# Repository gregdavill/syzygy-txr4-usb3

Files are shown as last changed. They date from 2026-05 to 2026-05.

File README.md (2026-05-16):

# SYZYGY-TXR4-USB3 breakout

SYZYGY is an FPGA expansion standard for medium to high speed interfaces. Learn more and check out the specifications here: [https://syzygyfpga.io/](https://syzygyfpga.io/)

---

## What is it

A breakout to connect SYZYGYs 5Gbit serdes lanes through to a USB-C connector

Running the gateware luna stack on the FPGA can enumerate as a USB3 device.

## Folder structure

```
kicad-src: KiCad v6 source files
production:
 - Gerbers:      [project]_gerbers.zip
 - Schematic:    [project].pdf
 - Board render: [project].png
```

## Photo

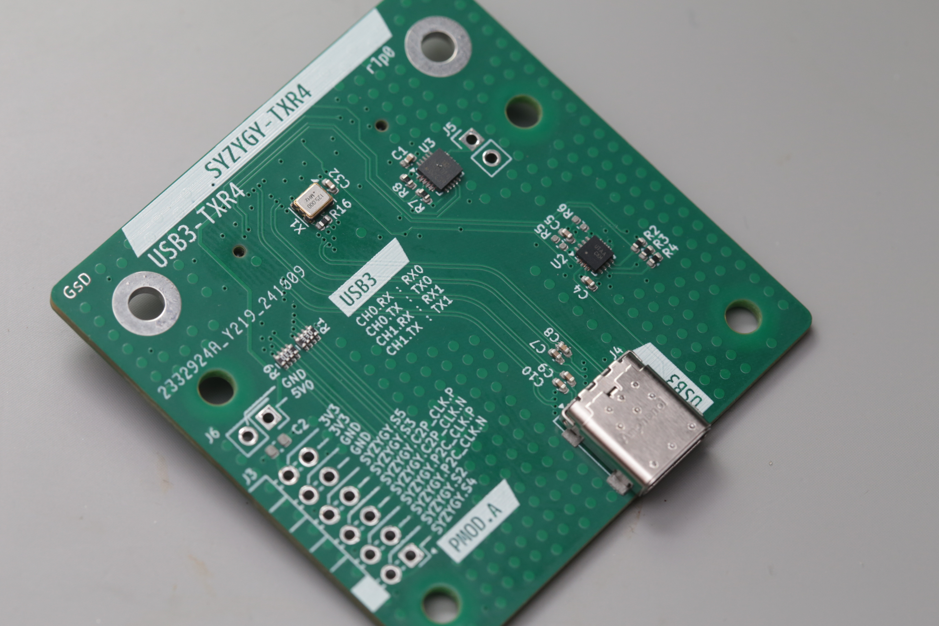
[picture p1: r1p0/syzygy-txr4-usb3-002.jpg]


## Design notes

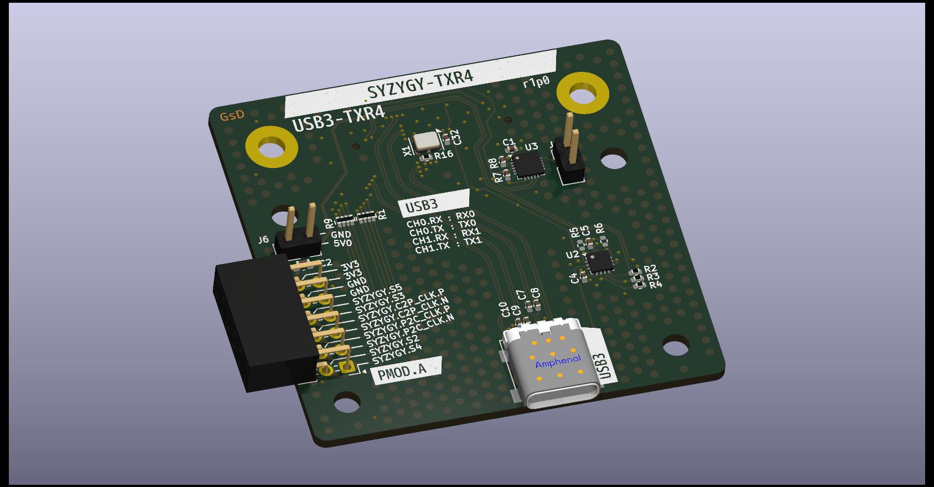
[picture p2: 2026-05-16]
r1p0/syzygy-txr4-usb3.jpg

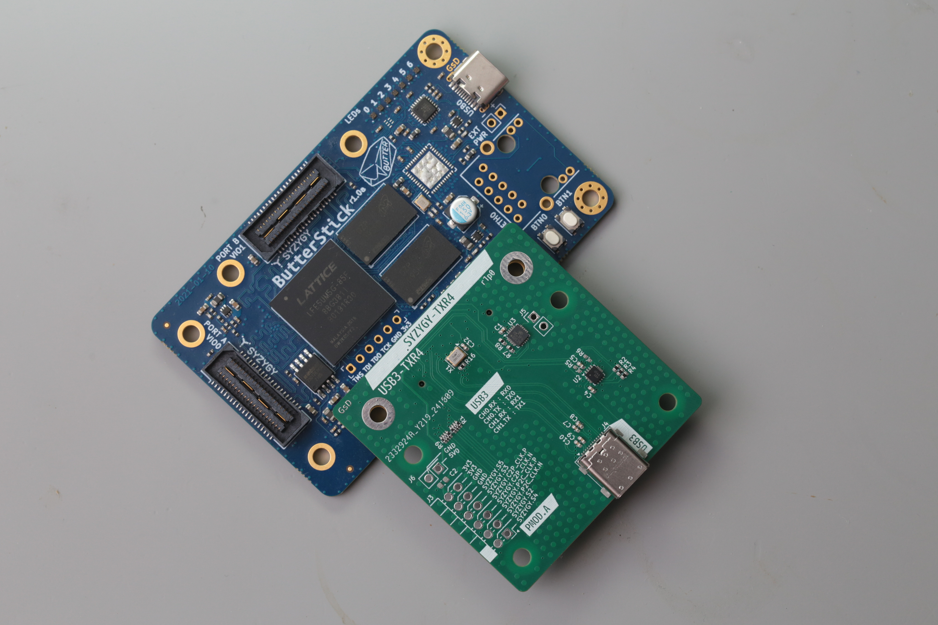
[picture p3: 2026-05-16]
r1p0/syzygy-txr4-usb3-001.jpg

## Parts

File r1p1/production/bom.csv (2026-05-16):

Reference | Value | Datasheet | Footprint | Qty | DNP | Mfg | PN
C1,C4,C5,C7,C8,C9,C10,C32 | 0.1uF | ~ | Capacitor_SMD:C_0402_1005Metric | 8 |  | Samsung Electro-Mechanics | CL05B104KA5NNNC
C2 | DNP |  | Capacitor_SMD:C_0603_1608Metric | 1
J1 | SYZYGY-TXR-4 |  | gsd-footprints:SYZYGY-TXR-POD | 1 |  | Samtec Inc. | QTH-020-01-F-D-DP-A-K
J2 | DBG | ~ | Connector_PinHeader_2.54mm:PinHeader_2x05_P2.54mm_Vertical | 1 |  | DEALON | DW254W-22-12-85
J3 | PMOD I/O | ~ | Connector_PinSocket_2.54mm:PinSocket_2x06_P2.54mm_Horizontal | 1 |  | DEALON | DW254W-22-12-85
J4 | USB_C_Receptacle | https://www.usb.org/sites/default/files/documents/usb_type-c.zip | Connector_USB:USB_C_Receptacle_Amphenol_12401610E4-2A | 1 |  | Amphenol ICC | 12401610E4#2A
J5 | PH_01x02 | ~ | Connector_PinHeader_2.54mm:PinHeader_1x02_P2.54mm_Vertical | 1 |  | DEALON | DZ254R-11-02-63
J6 | 5V AUX |  | Connector_PinHeader_2.54mm:PinHeader_2x01_P2.54mm_Vertical | 1 |  | DEALON | DZ254R-11-02-63
R1,R9 | 33R |  | Resistor_SMD:R_Array_Convex_4x0402 | 2 |  | Yageo | YC124-JR-0733RL
R2,R3,R4 | 2k2 | ~ | Resistor_SMD:R_0402_1005Metric | 3 |  | Yageo | RC0402FR-072K2L
R5,R6 | 5k1 | ~ | Resistor_SMD:R_0402_1005Metric | 2 | DNP | Yageo | RC0402FR-075K1L
R7 | 10k | ~ | Capacitor_SMD:C_0402_1005Metric | 1 |  | Yageo | RC0402FR-0710KL
R8 | 4.7k | ~ | Capacitor_SMD:C_0402_1005Metric | 1 |  | Yageo | RC0402FR-074K7L
R16 | 100R | ~ | Resistor_SMD:R_0402_1005Metric | 1 | DNP | Yageo | AC0402FR-07100RL
U2 | FUSB302BMPX | http://www.onsemi.com/pub/Collateral/FUSB302B-D.PDF | Package_DFN_QFN:WQFN-14-1EP_2.5x2.5mm_P0.5mm_EP1.45x1.45mm | 1 |  | onsemi | FUSB302BMPX
U3 | CH32V003F4U6 | http://www.wch-ic.com/downloads/CH32V003DS0_PDF.html | Package_DFN_QFN:QFN-20-1EP_3x3mm_P0.4mm_EP1.65x1.65mm_ThermalVias | 1 |  | WCH(Jiangsu Qin Heng) | CH32V003F4U6
X1 | SG3225 | https://support.epson.biz/td/api/doc_check.php?dl=brief_SG5032VAN | Oscillator:Oscillator_SMD_Silicon_Labs_LGA-6_2.5x3.2mm_P1.25mm | 1 |  | EPSON | SG3225VEN 125.000000M-CJGA3

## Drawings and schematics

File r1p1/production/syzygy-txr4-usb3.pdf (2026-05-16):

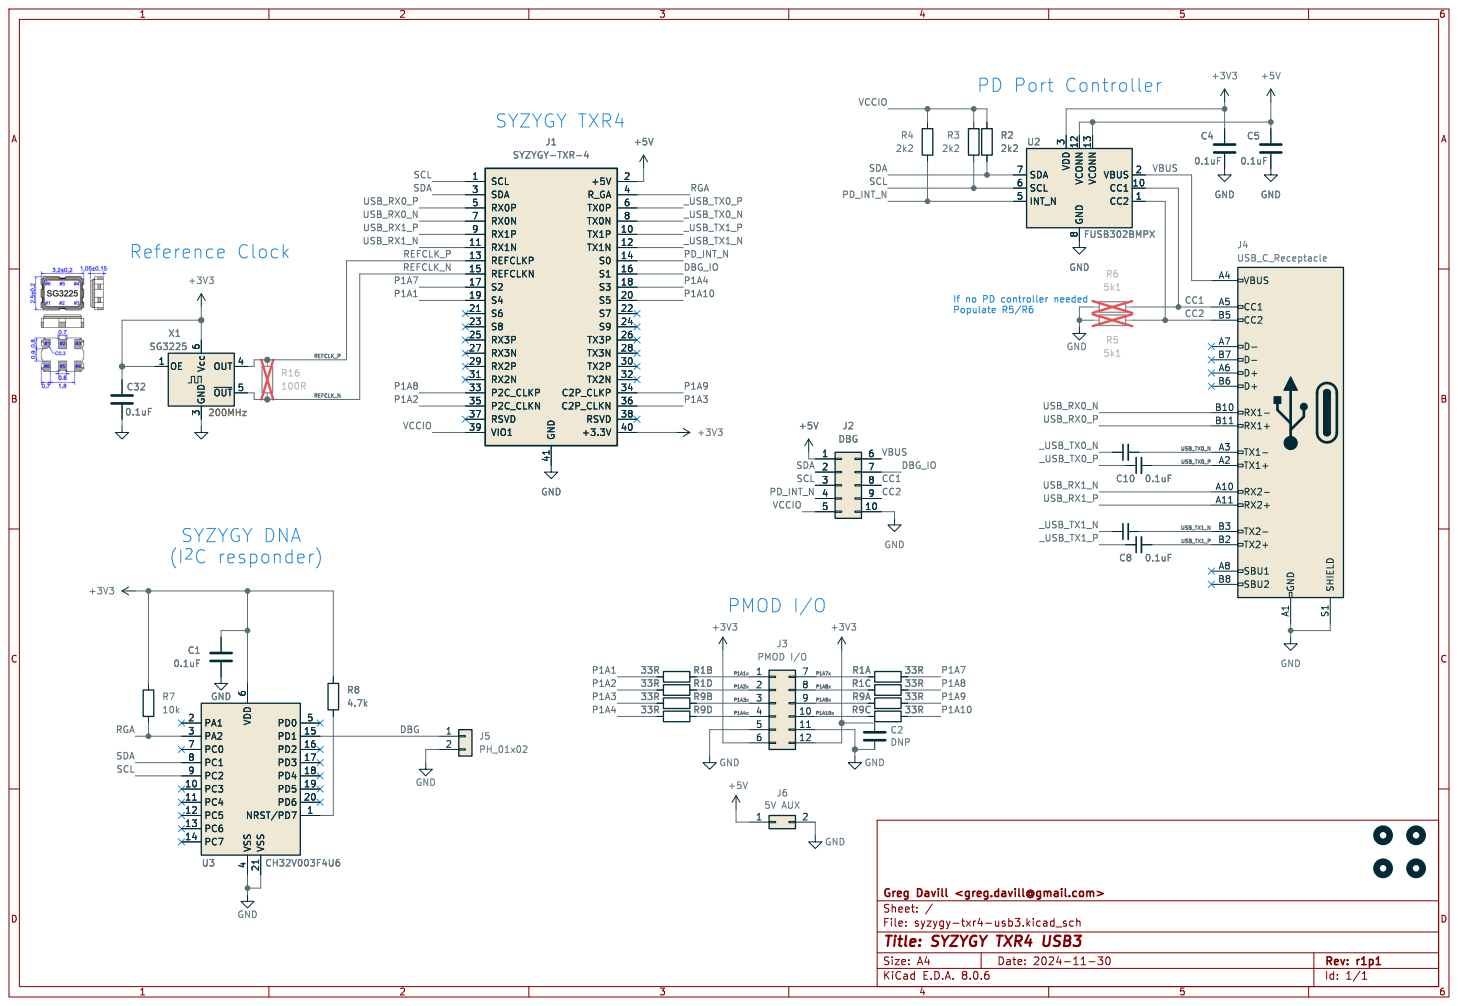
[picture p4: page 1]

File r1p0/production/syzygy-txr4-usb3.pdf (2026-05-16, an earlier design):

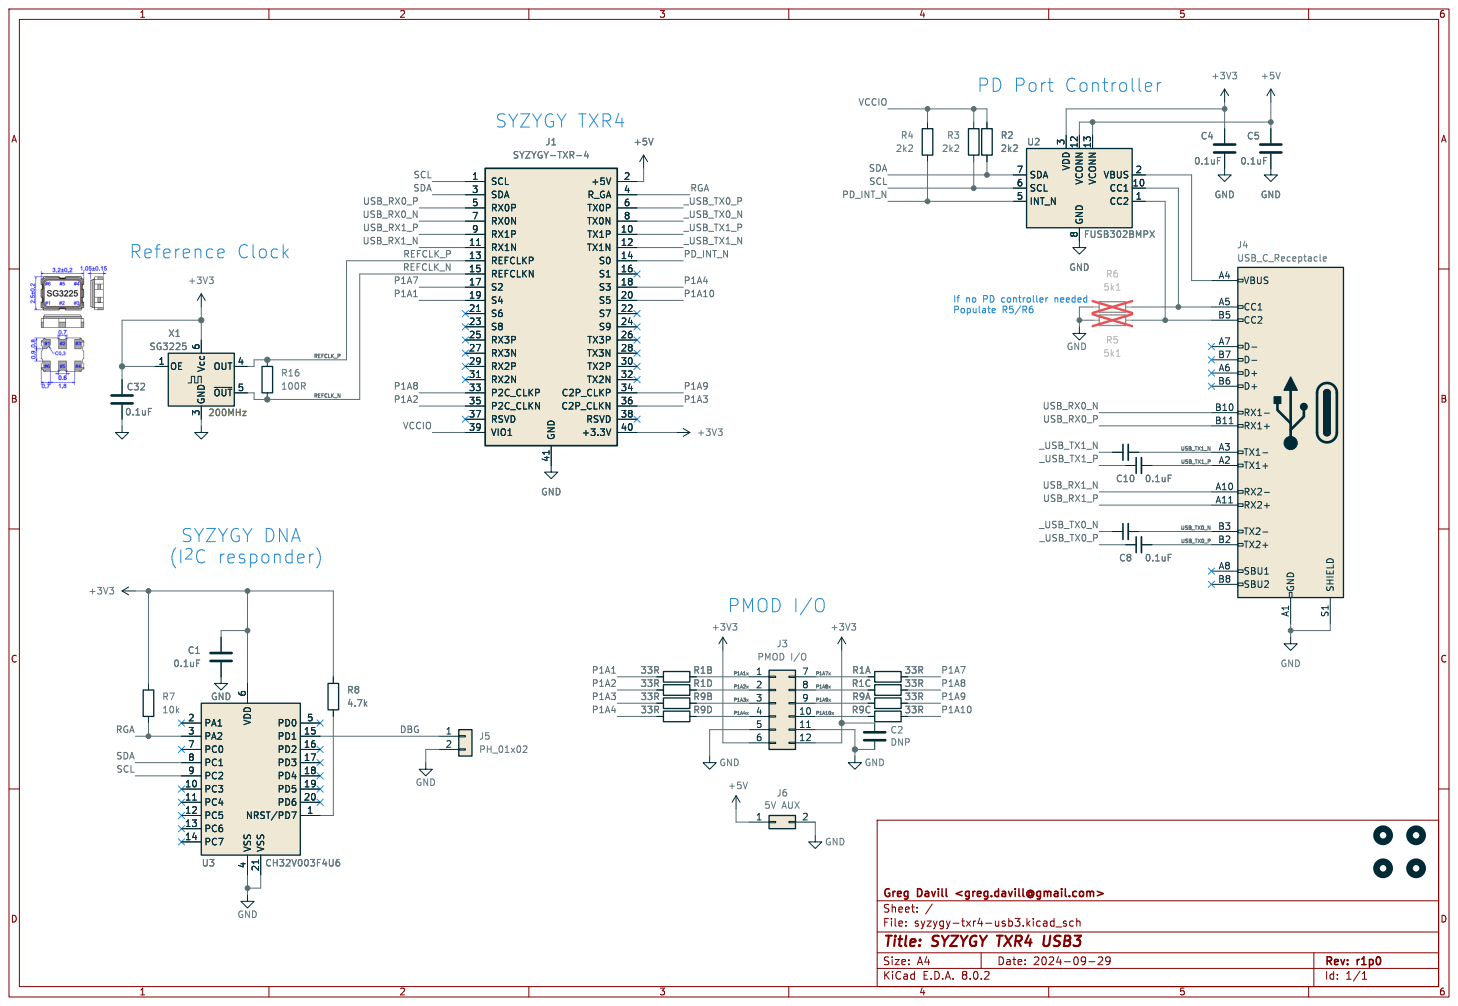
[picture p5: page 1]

3 OUT 4 ~{OUT}5 Vcc 6 U3 CH32V003F4U6 NRST/PD7 1 PC3 10 PC4 11 PC5 12 PC6 13 PC7 14 PD1 15 PD2 16 PD3 17 PD4 18 PD5 19 PA1 2 PD6 20 VSS 21 PA2 3 VSS

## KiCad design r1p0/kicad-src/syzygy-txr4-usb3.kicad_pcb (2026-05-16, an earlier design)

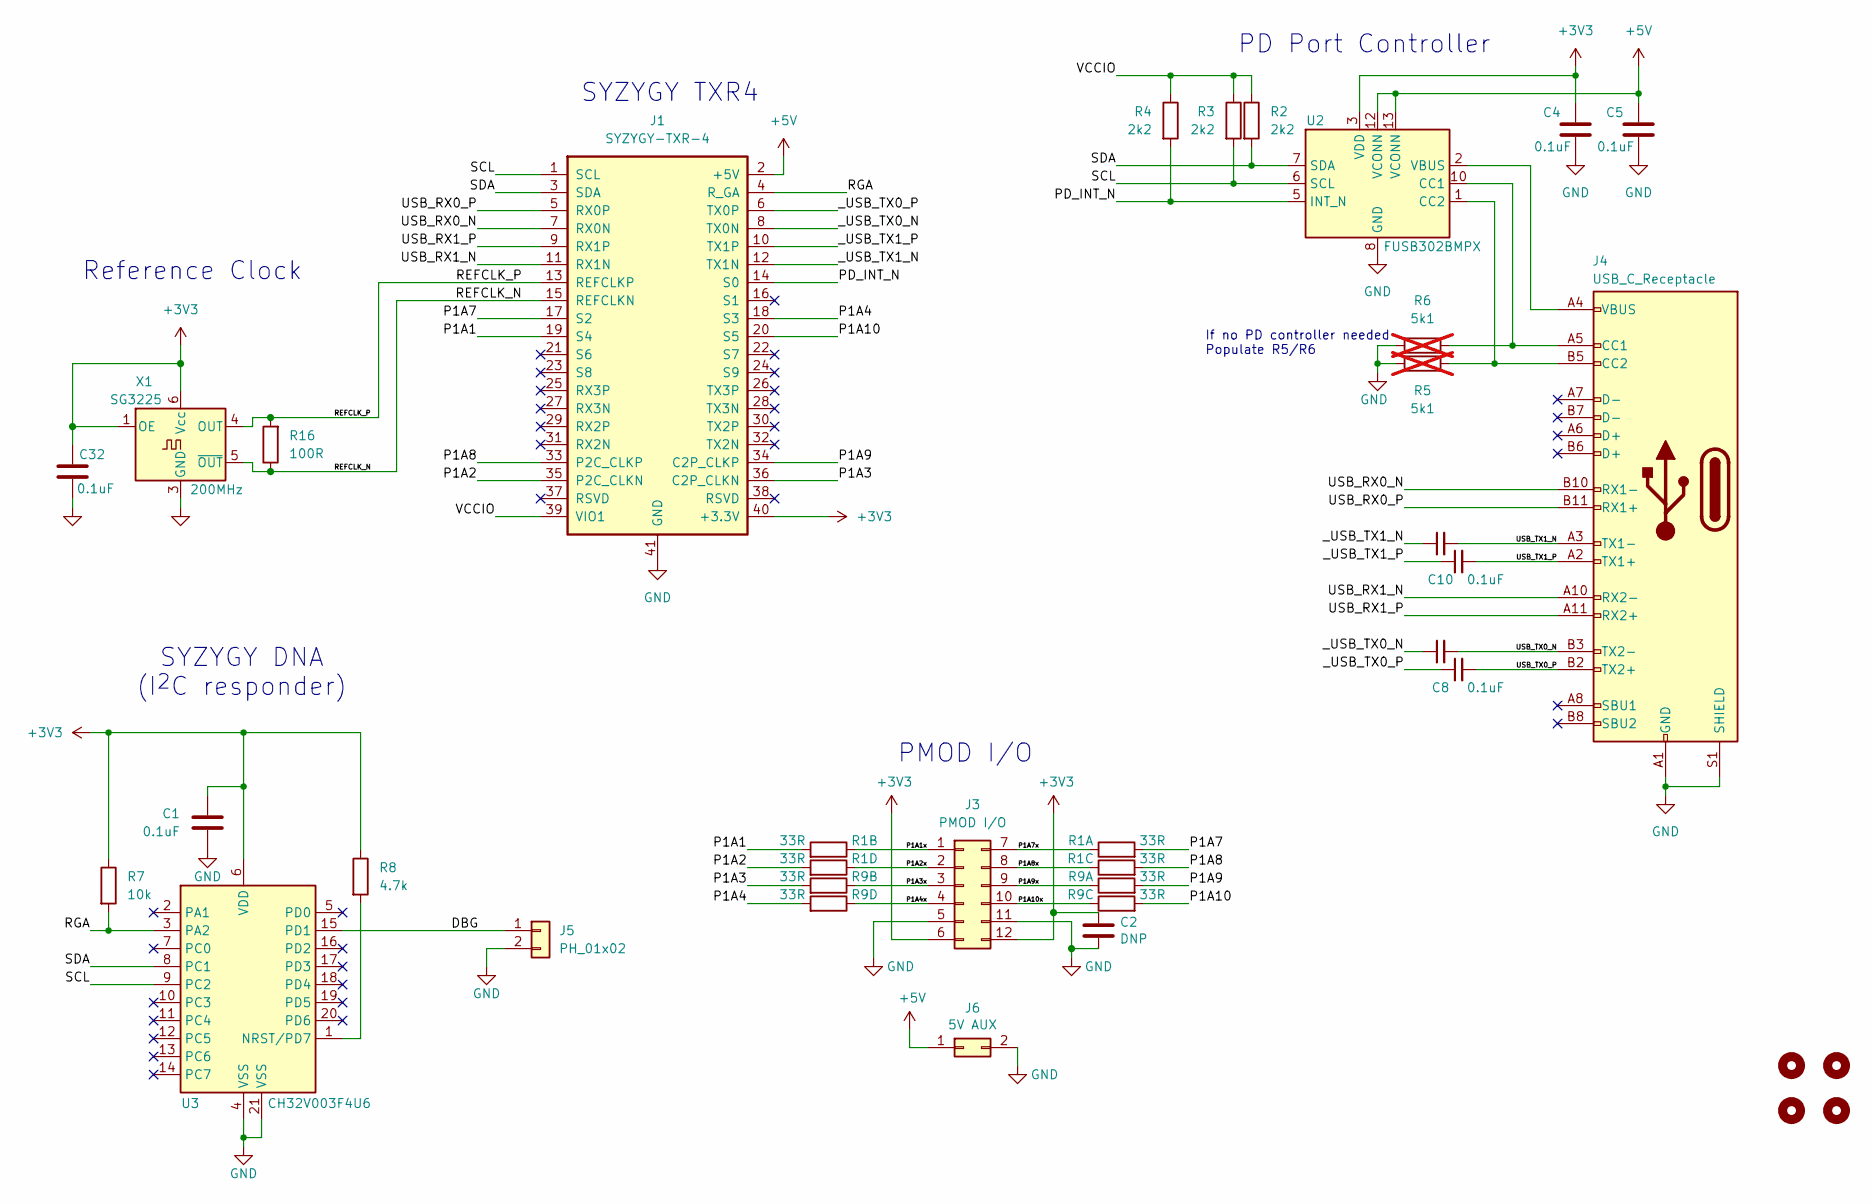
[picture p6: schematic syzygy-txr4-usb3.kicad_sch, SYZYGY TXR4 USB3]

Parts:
C1, C4, C5, C7, C8, C9, C10, C32: 0.1uF; C_0402_1005Metric
C2: DNP; C_0603_1608Metric
H1, H2, H3, H4: MountingHole; MountingHole_3.2mm_M3
J1: SYZYGY-TXR-4; SYZYGY-TXR-POD
J3: PMOD I/O; PinSocket_2x06_P2.54mm_Horizontal
J4: USB_C_Receptacle; USB_C_Receptacle_Amphenol_12401610E4-2A
J5: PH_01x02; PinHeader_1x02_P2.54mm_Vertical
J6: 5V AUX; PinHeader_2x01_P2.54mm_Vertical
R1, R9: 33R; R_Array_Convex_4x0402
R2, R3, R4: 2k2; R_0402_1005Metric
R5, R6: 5k1; R_0402_1005Metric; not fitted
R7: 10k; C_0402_1005Metric
R8: 4.7k; C_0402_1005Metric
R16: 100R; R_0402_1005Metric
U2: FUSB302BMPX; WQFN-14-1EP_2.5x2.5mm_P0.5mm_EP1.45x1.45mm
U3: CH32V003F4U6; QFN-20-1EP_3x3mm_P0.4mm_EP1.65x1.65mm_ThermalVias
X1: SG3225; Oscillator_SMD_Silicon_Labs_LGA-6_2.5x3.2mm_P1.25mm

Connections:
+3V3: C1.1, C2.2, C4.1, C32.1, J1.40 (+3.3V), J3.6, J3.12, R7.1, R8.1, U2.3 (VDD), U2.4 (VDD), U3.6 (VDD), X1.1 (OE), X1.6 (Vcc)
+5V: C5.1, J1.2 (+5V), J6.1, U2.12 (VCONN), U2.13 (VCONN)
/DBG: J5.1, U3.15 (PD1)
/P1A1: J1.19 (S4), R1.2
/P1A1x: J3.1, R1.7
/P1A2: J1.35 (P2C_CLKN), R1.4
/P1A2x: J3.2, R1.5
/P1A3: J1.36 (C2P_CLKN), R9.2
/P1A3x: J3.3, R9.7
/P1A4: J1.18 (S3), R9.4
/P1A4x: J3.4, R9.5
/P1A7: J1.17 (S2), R1.1
/P1A7x: J3.7, R1.8
/P1A8: J1.33 (P2C_CLKP), R1.3
/P1A8x: J3.8, R1.6
/P1A9: J1.34 (C2P_CLKP), R9.1
/P1A9x: J3.9, R9.8
/P1A10: J1.20 (S5), R9.3
/P1A10x: J3.10, R9.6
/PD_INT_N: J1.14 (S0), R4.2, U2.5 (INT_N)
/REFCLK_N: J1.15 (REFCLKN), R16.1, X1.5 (~OUT)
/REFCLK_P: J1.13 (REFCLKP), R16.2, X1.4 (OUT)
/RGA: J1.4 (R_GA), R7.2, U3.3 (PA2)
/SCL: J1.1 (SCL), R3.2, U2.6 (SCL), U3.9 (PC2)
/SDA: J1.3 (SDA), R2.2, U2.7 (SDA), U3.8 (PC1)
/USB_RX0_N: J1.7 (RX0N), J4.B10 (RX1-)
/USB_RX0_P: J1.5 (RX0P), J4.B11 (RX1+)
/USB_RX1_N: J1.11 (RX1N), J4.A10 (RX2-)
/USB_RX1_P: J1.9 (RX1P), J4.A11 (RX2+)
/USB_TX0_N: C7.2, J4.B3 (TX2-)
/USB_TX0_P: C8.2, J4.B2 (TX2+)
/USB_TX1_N: C9.2, J4.A3 (TX1-)
/USB_TX1_P: C10.2, J4.A2 (TX1+)
/VCCIO: J1.39 (VIO1), R2.1, R3.1, R4.1
/_USB_TX0_N: C7.1, J1.8 (TX0N)
/_USB_TX0_P: C8.1, J1.6 (TX0P)
/_USB_TX1_N: C9.1, J1.12 (TX1N)
/_USB_TX1_P: C10.1, J1.10 (TX1P)
GND: C1.2, C2.1, C4.2, C5.2, C32.2, J1.41 (GND), J3.5, J3.11, J4.A1 (GND), J4.A12 (GND), J4.B1 (GND), J4.B12 (GND), J4.S1 (SHIELD), J5.2, J6.2, R5.2, R6.2, U2.8 (GND), U2.9 (GND), U2.15 (GND), U3.4 (VSS), U3.21 (VSS), X1.3 (GND)
unnamed: J4.A5 (CC1), R6.1, U2.10 (CC1), U2.11 (CC1)
unnamed: J4.B5 (CC2), R5.1, U2.1 (CC2), U2.14 (CC2)
unnamed: J4.A4 (VBUS), J4.A9 (VBUS), J4.B4 (VBUS), J4.B9 (VBUS), U2.2 (VBUS)
unnamed: R8.2, U3.1 (NRST/PD7)

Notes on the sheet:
PMOD I/O
If no PD controller needed Populate R5/R6
SYZYGY DNA (I^{2}C responder)
SYZYGY TXR4
PD Port Controller
Reference Clock

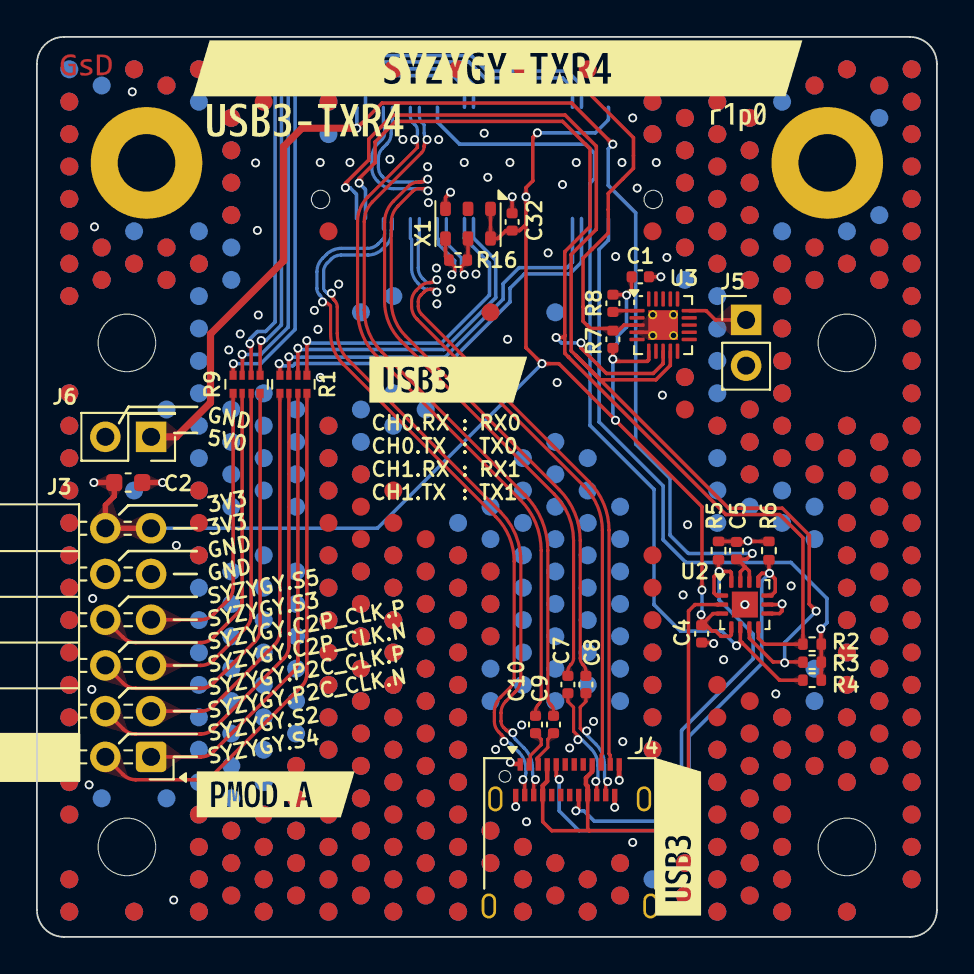
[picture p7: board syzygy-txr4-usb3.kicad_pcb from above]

Board: 4 copper layers, 50.0 x 50.0 mm, 37 parts (1 on the bottom side), 43 nets.

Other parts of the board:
kibuzzard-66F7DAC0: G***; kibuzzard-66F7DAC0
kibuzzard-66F7DADB: G***; kibuzzard-66F7DADB
kibuzzard-66F7DBDF: G***; kibuzzard-66F7DBDF
kibuzzard-66F8E50F, kibuzzard-66F8E50F#2: G***; kibuzzard-66F8E50F
kibuzzard-66F8E506: G***; kibuzzard-66F8E506

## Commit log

2026-05-16 Add r1p0 design files
    [bom.csv, syzygy-txr4-usb3.kicad_pcb, syzygy-txr4-usb3.kicad_sch]
2026-05-16 Add r1p1 design files
    [bom.csv, syzygy-txr4-usb3.kicad_pcb]
